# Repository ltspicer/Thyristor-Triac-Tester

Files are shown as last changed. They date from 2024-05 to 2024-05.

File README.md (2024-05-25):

# Thyristor-Triac-Tester

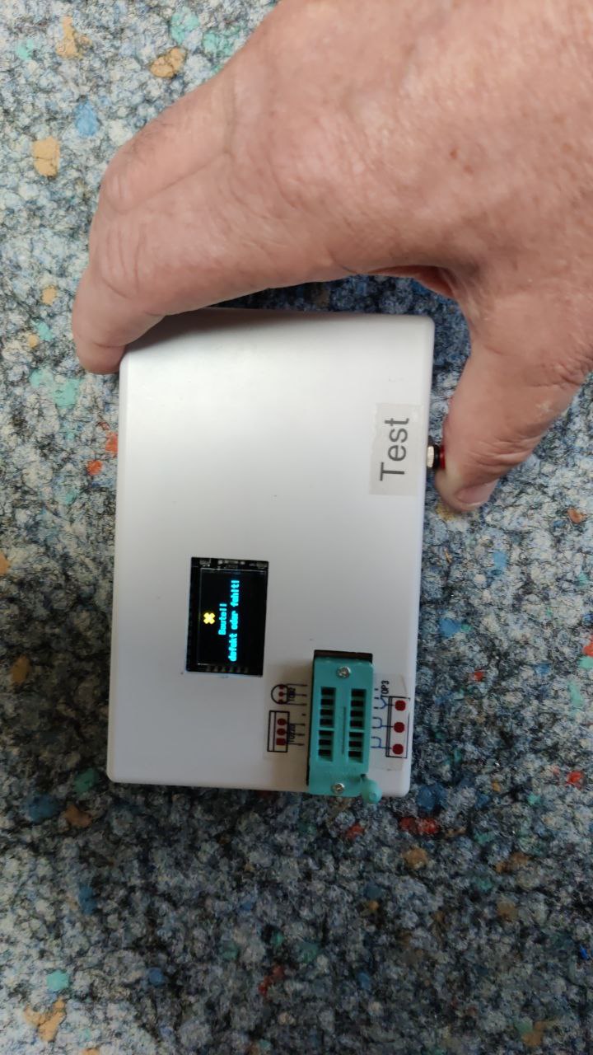
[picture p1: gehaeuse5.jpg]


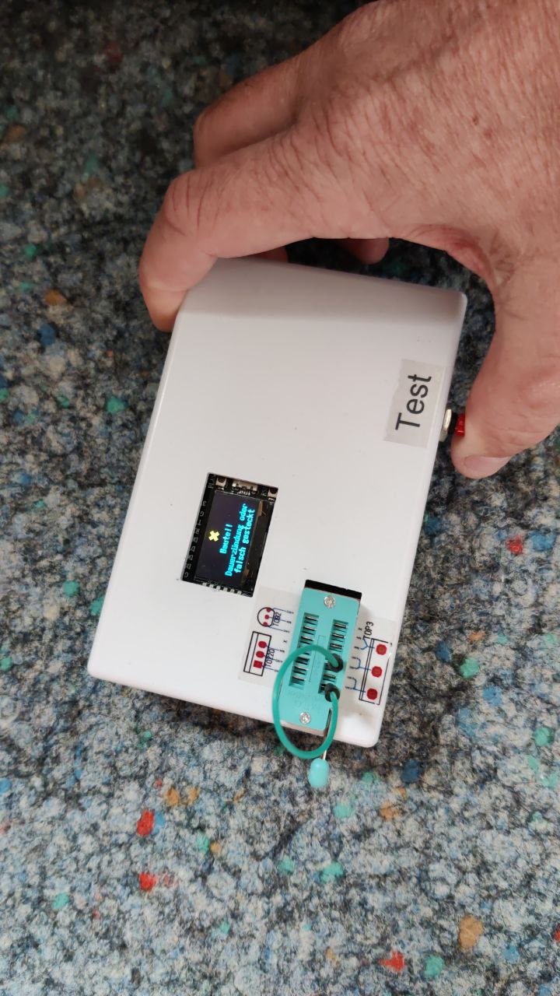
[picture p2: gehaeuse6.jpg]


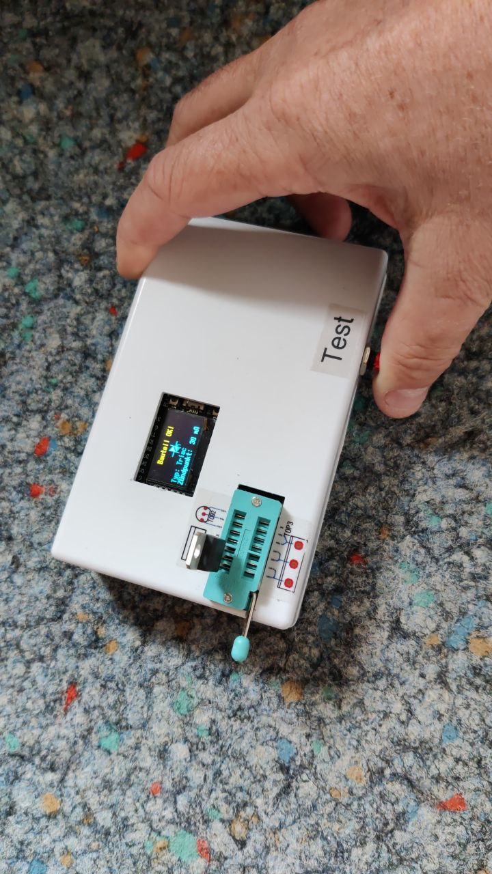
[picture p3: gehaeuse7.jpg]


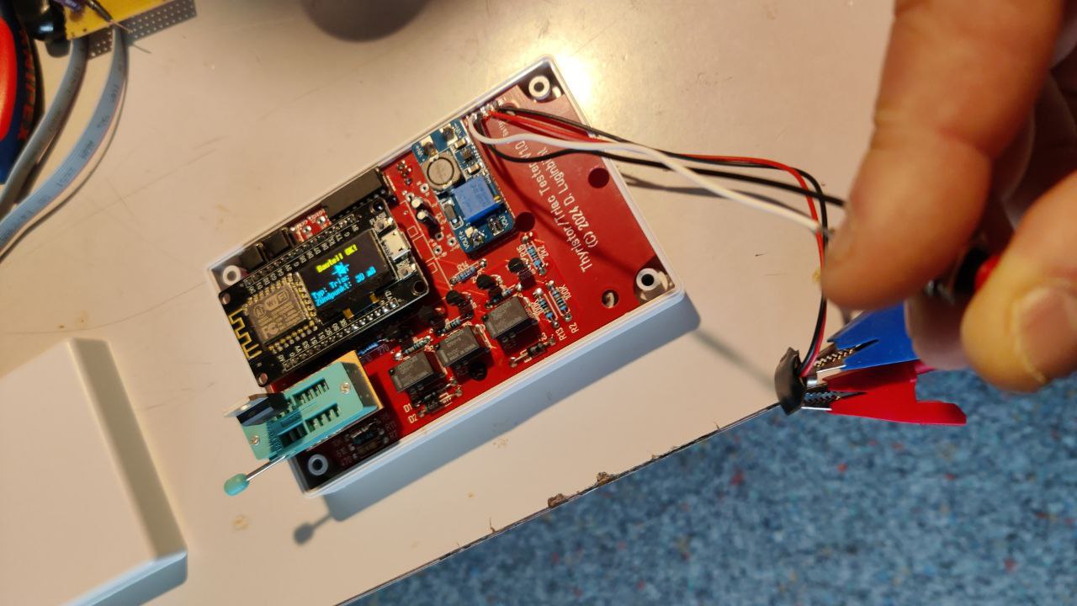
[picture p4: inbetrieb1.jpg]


## Original Text:

Dieses Testgerät kann Thyristoren und Triacs bis zu hohen Zündströmen testen.

Thyristoren und Triacs testen ist das Einzige, was der LCR-TC2 ( https://de.aliexpress.com/item/1005004205300336.html ) nicht kann.

Grösste Baustelle ist noch die Distanzerhöhung des IC Testsockels. Dieser sollte höher als das Display sein.
Leider greiffen die kurzen Beinchen nicht stabil genug in einem Pinheader.

Die Zwischenplatte ist nur, um den IC Testsockel auf ein Niveau höher als das Display zu bringen.
Ohne Gehäuse kann der IC Testsockel direkt auf das PCB gelötet werden.

Die Schaltkreise und PCB Layouts sind mit Target3001medium erstellt worden und können mit Target3001discover geöffnet werden. Target3001discover ist kostenlos!

Der StepUp ist auf **18V** zustellen!

Die ino Datei ist mittels **Arduino IDE** auf den ESP8266 zuschreiben.

Ich habe zwar noch rote PCBs V1.0 auf Lager (für Interessenten). Falls aber eine grössere Sammelbestellung zustande kommt, werde ich V1.1 PCBs in Auftrag geben. Ich werde dann auch die Zwischen-PCBs für den IC Testsockel bestellen.

Dieses Projekt ist hier zuhause: https://www.ltspiceusers.ch/threads/baue-mir-einen-thyristor-triac-tester-mit-einem-esp8266-mit-oled-display.2739/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

Die **2 zip** sind die **Gerber** Dateien.

Falls ein Triac als Thyristor erkannt wird, ist dieser Triac defekt!

## English (DeepL translator):

This tester can test thyristors and triacs up to high ignition currents.

Testing thyristors and triacs is the only thing the LCR-TC2 ( https://de.aliexpress.com/item/1005004205300336.html ) cannot do.

The biggest problem is increasing the distance of the IC test socket. This should be higher than the display.
Unfortunately, the short legs do not grip firmly enough in a pin header.

The intermediate plate is only to bring the IC test socket to a level higher than the display.
Without the housing, the IC test socket can be soldered directly onto the PCB.

The circuits and PCB layouts have been created with Target3001medium and can be opened with Target3001discover. Target3001discover is free!

The StepUp must be set to **18V**!

The ino file is to be written to the ESP8266 with **Arduino IDE**.

I still have red PCBs V1.0 in stock (for interested parties). However, if a larger collective order is placed, I will order V1.1 PCBs. I will then also order the intermediate PCBs for the IC test socket.

This project is here @home: https://www.ltspiceusers.ch/threads/baue-mir-einen-thyristor-triac-tester-mit-einem-esp8266-mit-oled-display.2739/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

The **2 zip** are the **Gerber** files.

If a triac is recognized as a thyristor, this triac is defective!

--------------------------------

## Stückliste:

1x  ESP8266 NodeMCU mit OLED        https://de.aliexpress.com/item/1005005470719229.html

1x  Gehäuse 125x80x32mm             https://de.aliexpress.com/item/1005005448610944.html

2x  Pinheader 15pol weiblich        https://de.aliexpress.com/item/1005001418544370.html

3x  Omron Relais G5V-1-5VDC         https://de.aliexpress.com/item/1005005743754968.html

1x  L293B H-Bridge                  https://de.aliexpress.com/item/1005006253986033.html

1x  StepUp MT3608                   https://de.aliexpress.com/item/1005006532445571.html

1x  14pin IC Testsockel             https://de.aliexpress.com/item/1005006117085994.html

2x  4N35 Optokoppler

1x  7805 5V Spannungsregler

5x  2N7000 Kleinleistungs-FET

3x  1N4007 Diode (oder ähnlich. Nur für Freilauf)

2x  IC Sockel DIP6

1x  IC Sockel DIP16

1x  Einbau Drucktaster (Schliesser)

1x  9V Batterie Anschlusskabel

1x  9V Batterie

2x  Elko 4.7µF 50V (mindestens 16V)

5x  Widerstand 100 kOhm

3x  Widerstand 10 kOhm

2x  Widerstand 2.2 kOhm

1x  Widerstand 510 Ohm

1x  Widerstand 470 Ohm

1x  Widerstand 270 Ohm

1x  Widerstand 60 Ohm

1x  Widerstand 22 Ohm

2x  Pinheader 7pol weiblich (für IC Testsockel)

Pinleiste 1 reihig zuschneidbar (für StepUp, IC Testsockel und optionale Testpins)

### Die Bauteile kosten keine 20€ (exkl Batterie. Die ist wohl das teuerste Bauteil)!

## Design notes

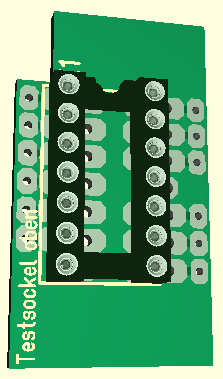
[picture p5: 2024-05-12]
pcb2.png

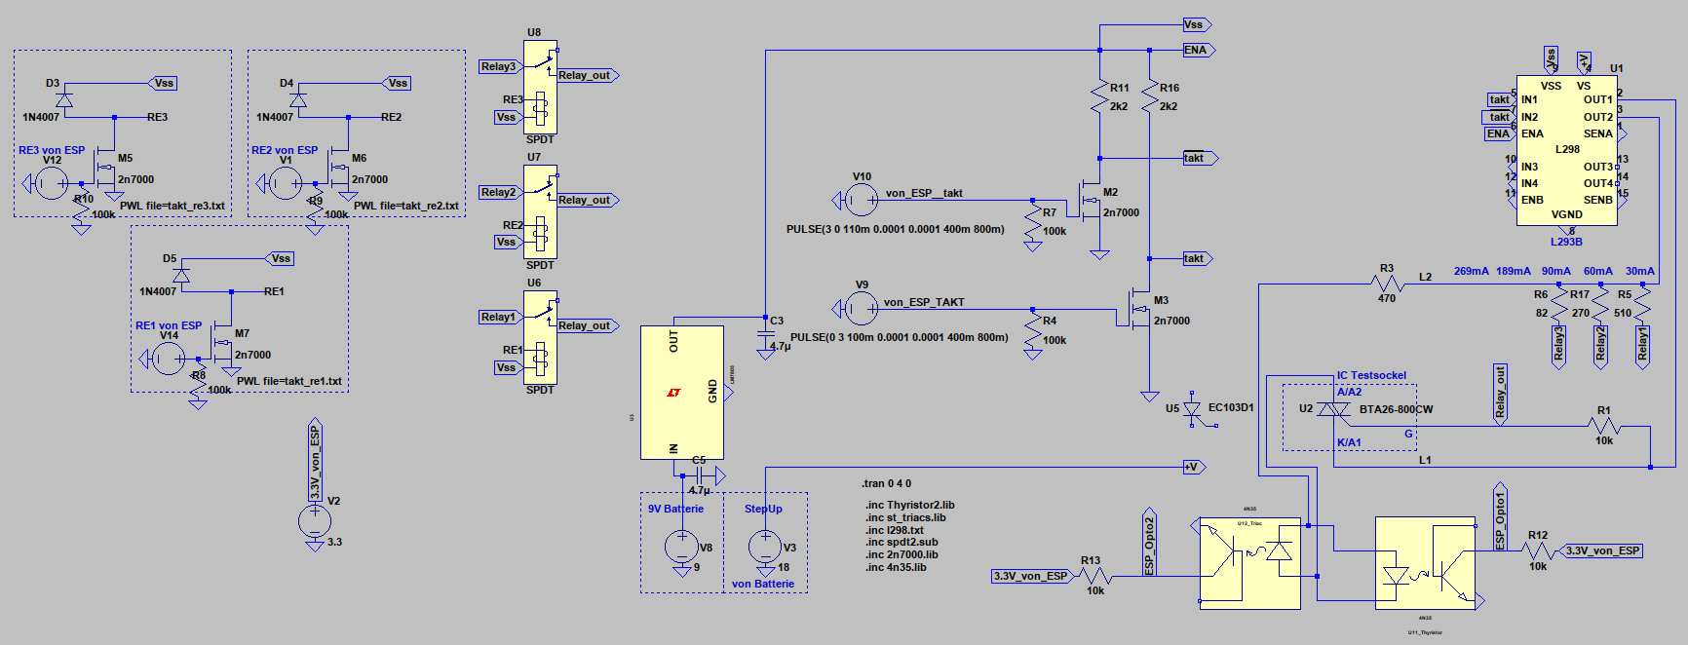
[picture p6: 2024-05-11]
ltspice_simulation.png

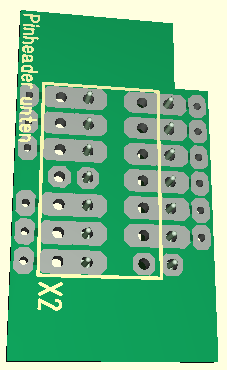
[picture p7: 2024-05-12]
pcb22.png

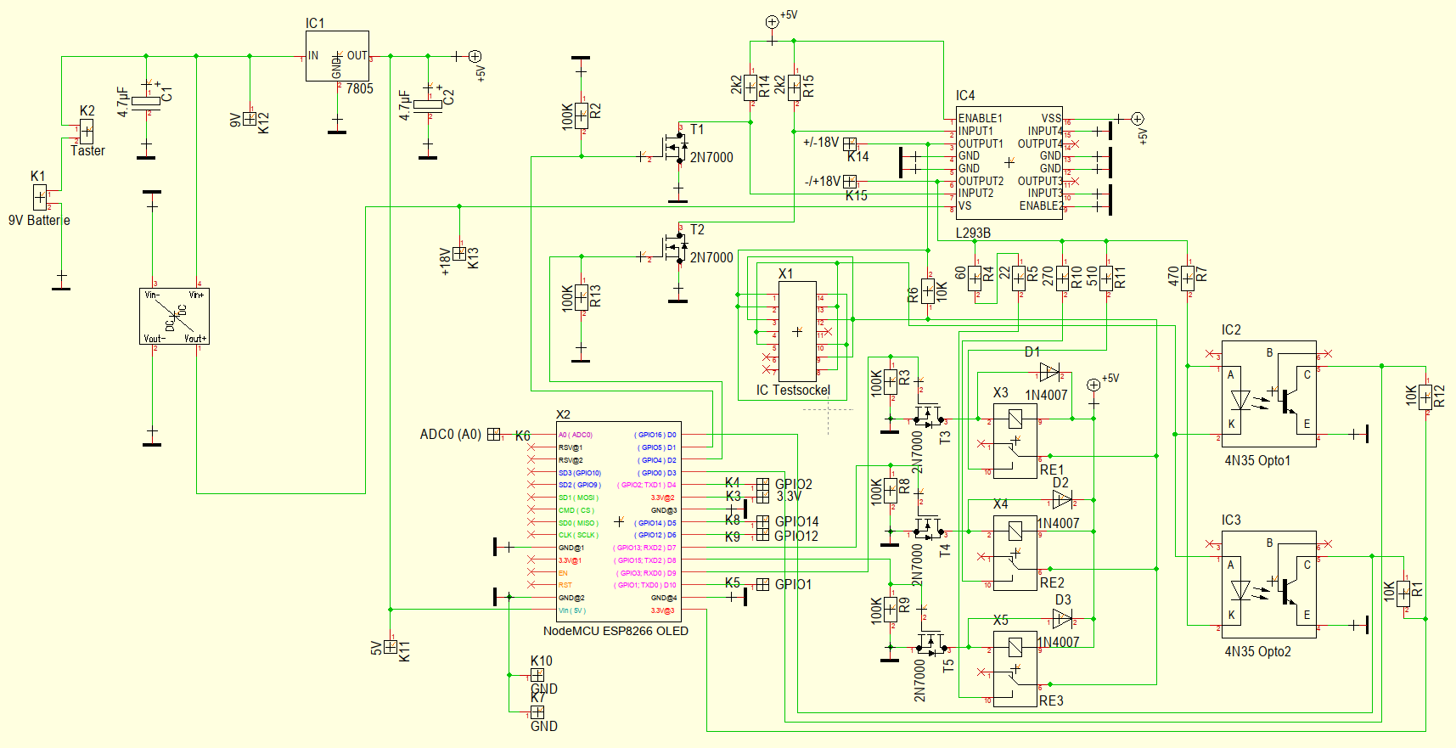
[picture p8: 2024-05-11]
schema_target3001.png

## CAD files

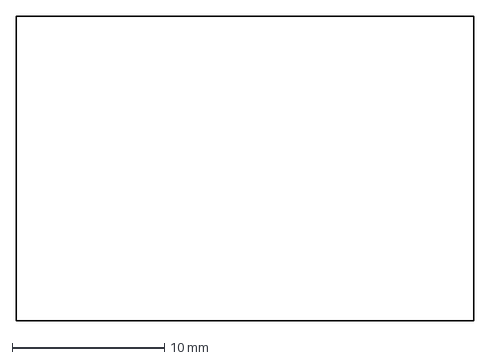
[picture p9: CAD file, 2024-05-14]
gehaeuse/display.dxf
30.0 x 20.0 mm

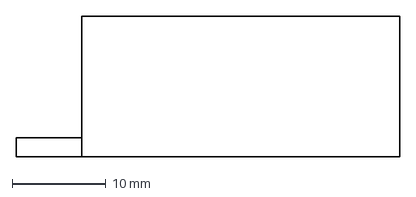
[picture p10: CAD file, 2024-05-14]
gehaeuse/ic_sockel.dxf
41.0 x 15.0 mm

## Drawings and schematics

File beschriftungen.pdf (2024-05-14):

# Test

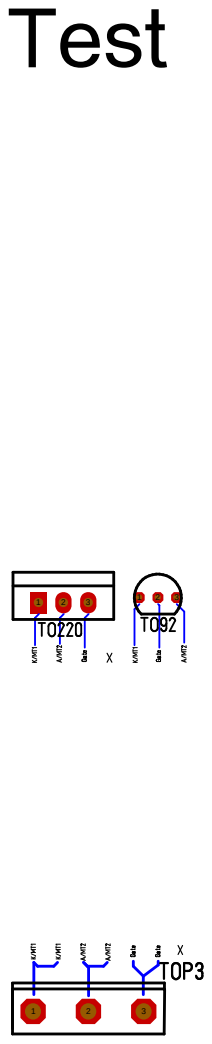
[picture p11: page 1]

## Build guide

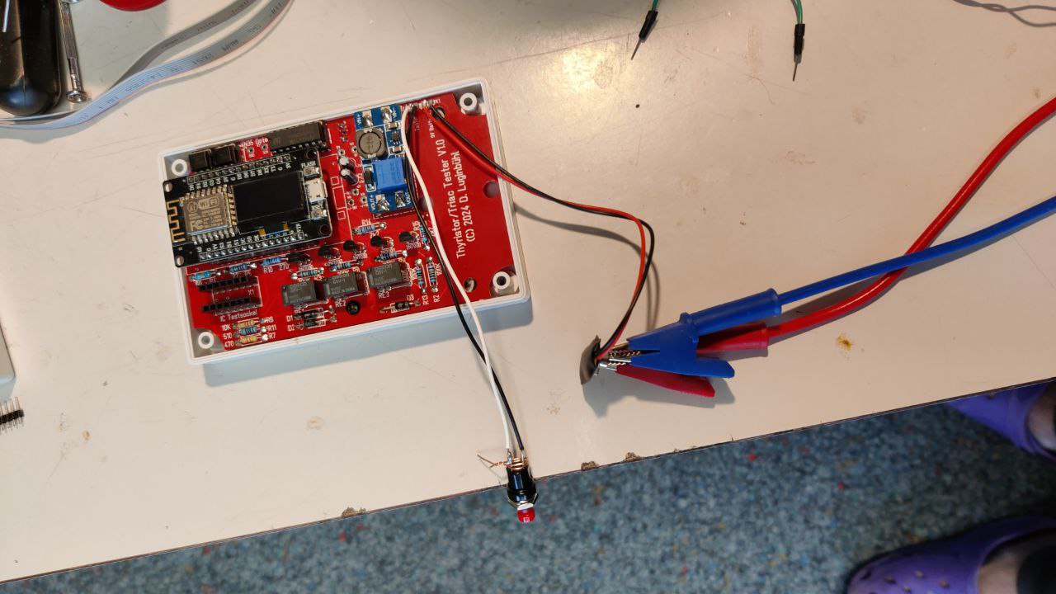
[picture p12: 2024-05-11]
aufbau2.jpg

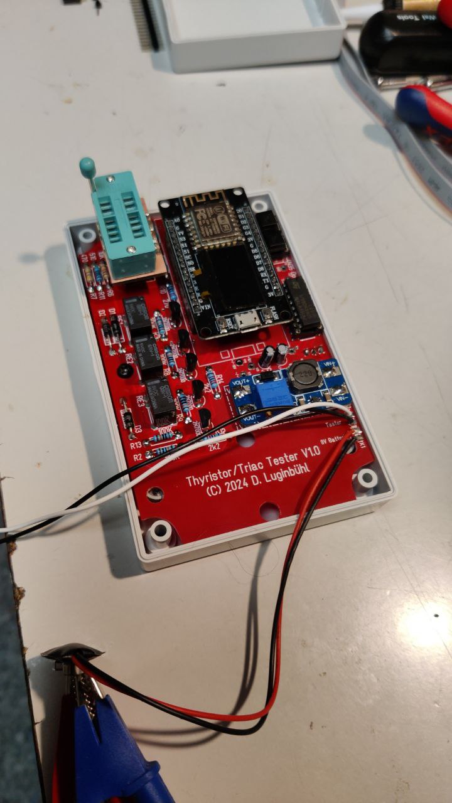
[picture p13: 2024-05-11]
aufbau3.jpg

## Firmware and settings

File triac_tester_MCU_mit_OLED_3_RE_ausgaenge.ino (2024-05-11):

// Thyristor/Triac Tester
// Daniel Luginbühl
// V1.1 (C) 2024

// https://github.com/olikraus/u8g2/wiki

#include <Arduino.h>
#include <U8g2lib.h>

#define SCREEN_WIDTH 128
#define SCREEN_HEIGHT 64
#define OLED_RESET -1
#define SCREEN_ADDRESS 0x3C

// sda = 12
// scl = 14

U8G2_SSD1306_128X64_NONAME_F_SW_I2C u8g2(U8G2_R0,14,12,U8X8_PIN_NONE);

// GPIOs definieren
const int RE1  =  3;           // Relais Ausgang 1
const int RE2  = 13;           // Relais Ausgang 2
const int RE3  = 15;           // Relais Ausgang 3

const int TAKT =  4;           // Takt        für Umpolung
const int takt =  5;           // Takt invers für Umpolung

const int Opto1  =  0;         // Opto1  mit PullUp
const int Opto2  = 16;         // Opto2  mit PullUp

const int debug = 2;           // Pin an GND schaltet DEBUG ein

// Diverse Koordinaten für Grafikausgabe
const int x_offset = 47;
const int oben = 17;
const int y_mitte = 27;
const int unten = 37;
const int triac1 = 23;
const int triac2 = 31;

const int zeile0 = 14;
const int zeile1 = 32;
const int zeile2 = 49;
const int zeile3 = 62;

// Diverse Variabeln
int gezuendet = 0;             // mA für Zündung
boolean positiv = false;       // Positive Halbwelle
boolean negativ = false;       // Negative Halbwelle
boolean DEBUG = false;         // Debug Status ein/aus

void setup() {
  Serial.begin(9600);

  u8g2.begin();
  // https://github.com/olikraus/u8g2/wiki/fntgrpx11#7x14b
  u8g2.setFont(u8g2_font_7x14B_tf);

  pinMode(RE1, OUTPUT);
  pinMode(RE2, OUTPUT);
  pinMode(RE3, OUTPUT);
  pinMode(TAKT, OUTPUT);
  pinMode(takt, OUTPUT);
  pinMode(Opto1, INPUT_PULLUP);
  pinMode(Opto2, INPUT_PULLUP);
  pinMode(debug, INPUT_PULLUP);

  digitalWrite(TAKT, LOW);
  digitalWrite(takt, LOW);
  digitalWrite(RE1,LOW);
  digitalWrite(RE2,LOW);
  digitalWrite(RE3,LOW);
}

void loop() {

  u8g2.clearBuffer();
  u8g2.drawUTF8(0, zeile0, "Prüfung läuft...");

  if (digitalRead(debug) == LOW) {
    DEBUG = true;
  } else {
    DEBUG = false;
  }

  // Bauteil Dauerzündung?
  u8g2.drawUTF8(0, zeile1, "Dauerzündung?");
  u8g2.sendBuffer();  
  delay(100);
  for (int d = 0; d < 2; d++) {
    if (gezuendet == 0 or gezuendet == 500) {
      umpolen();
      delay(200);
      if (OptosAbfragen()) {
        gezuendet = 500;
      }
    }
  }
  if (gezuendet == 500) {
    positiv = false;
    negativ = false;
    u8g2.clearBuffer();
    goto defekt;
  }

  // 30mA Zündung
  u8g2.clearBuffer();
  u8g2.drawUTF8(0, zeile0, "Prüfung läuft...");
  u8g2.drawUTF8(0, zeile1, "30mA Zündung");
  u8g2.sendBuffer();
  for (int d = 0; d < 2; d++) {
    if (gezuendet == 0 or gezuendet == 30) {
      umpolen();
      digitalWrite(RE1,HIGH);
      if (DEBUG) {
        Serial.println("RE1 HIGH");
      }  
      delay(200);
      digitalWrite(RE1,LOW);
      if (DEBUG) {
        Serial.println("RE1 LOW");
      }  
      delay(100);
      if (OptosAbfragen()) {
        gezuendet = 30;
      }
    }
  }
  if (gezuendet == 30) {
    goto fertig;
  }

  // 60mA Zündung
  u8g2.clearBuffer();
  u8g2.drawUTF8(0, zeile0, "Prüfung läuft...");
  u8g2.drawUTF8(0, zeile1, "60mA Zündung");
  u8g2.sendBuffer();  
  for (int d = 0; d < 2; d++) {
    if (gezuendet == 0 or gezuendet == 60) {
      umpolen();
      digitalWrite(RE2,HIGH);
      if (DEBUG) {
        Serial.println("RE2 HIGH");
      }  
      delay(200);
      digitalWrite(RE2,LOW);
      if (DEBUG) {
        Serial.println("RE2 LOW");
      }  
      delay(100);
      if (OptosAbfragen()) {
        gezuendet = 60;
      }
    }
  }
  if (gezuendet == 60) {
    goto fertig;
  }

  // 90mA Zündung
  u8g2.clearBuffer();
  u8g2.drawUTF8(0, zeile0, "Prüfung läuft...");
  u8g2.drawUTF8(0, zeile1, "90mA Zündung");
  u8g2.sendBuffer();
  for (int d = 0; d < 2; d++) {
    if (gezuendet == 0 or gezuendet == 90) {
      umpolen();
      digitalWrite(RE1,HIGH);
      digitalWrite(RE2,HIGH);
      if (DEBUG) {
        Serial.println("RE1 HIGH");
        Serial.println("RE2 HIGH");
      }  
      delay(200);
      digitalWrite(RE1,LOW);
      digitalWrite(RE2,LOW);
      if (DEBUG) {
        Serial.println("RE1 LOW");
        Serial.println("RE2 LOW");
      }  
      delay(100);
      if (OptosAbfragen()) {
        gezuendet = 90;
      }
    }
  }
  if (gezuendet == 90) {
    goto fertig;
  }

  // 189mA Zündung
  u8g2.clearBuffer();
  u8g2.drawUTF8(0, zeile0, "Prüfung läuft...");
  u8g2.drawUTF8(0, zeile1, "189mA Zündung");
  u8g2.sendBuffer();
  for (int d = 0; d < 2; d++) {
    if (gezuendet == 0 or gezuendet == 189) {
      umpolen();
      digitalWrite(RE3,HIGH);
      if (DEBUG) {
        Serial.println("RE3 HIGH");
      }  
      delay(200);
      digitalWrite(RE3,LOW);
      if (DEBUG) {
        Serial.println("RE3 LOW");
      }  
      delay(100);
      if (OptosAbfragen()) {
        gezuendet = 189;
      }
    }
  }
  if (gezuendet == 189) {
    goto fertig;
  }

  // 269mA Zündung
  u8g2.clearBuffer();
  u8g2.drawUTF8(0, zeile0, "Prüfung läuft...");
  u8g2.drawUTF8(0, zeile1, "269mA Zündung");
  u8g2.sendBuffer();
  for (int d = 0; d < 2; d++) {
    if (gezuendet == 0 or gezuendet == 269) {
      umpolen();
      digitalWrite(RE1,HIGH);
      digitalWrite(RE2,HIGH);
      digitalWrite(RE3,HIGH);
      if (DEBUG) {
        Serial.println("RE1 HIGH");
        Serial.println("RE2 HIGH");
        Serial.println("RE3 HIGH");
      }  
      delay(200);
      digitalWrite(RE1,LOW);
      digitalWrite(RE2,LOW);
      digitalWrite(RE3,LOW);
      if (DEBUG) {
        Serial.println("RE1 LOW");
        Serial.println("RE2 LOW");
        Serial.println("RE3 LOW");
      }  
      delay(100);
      if (OptosAbfragen()) {
        gezuendet = 269;
      }
    }
  }

  fertig:

  u8g2.clearBuffer();

  if (DEBUG) {
    if (!digitalRead(Opto1) == HIGH) {
      Serial.println("Opto1=1 (Positive Halbwelle)");
    }
    if (!digitalRead(Opto2) == HIGH) {
      Serial.println("Opto2=1 (Negative Halbwelle)");
    }
  }

  // Display Ausgabe

  // https://github.com/olikraus/u8g2/wiki/u8g2reference

  if (gezuendet > 0) {
    //u8g2.setCursor(0, zeile2);
    //u8g2.print("Zündpunkt: ");
    u8g2.drawUTF8(0, zeile3, "Zündpunkt: ");
    u8g2.setCursor(10*8, zeile3);
    u8g2.print(gezuendet);
    u8g2.print(" mA");
    u8g2.setCursor(0, zeile2);
    u8g2.print("Typ: ");
    if (positiv != negativ) {
      u8g2.print("Thyristor");

      u8g2.drawLine(x_offset   , y_mitte  , x_offset+10, y_mitte);
      u8g2.drawLine(x_offset+20, y_mitte  , x_offset+30, y_mitte);
      u8g2.drawLine(x_offset+20, oben+3   , x_offset+20, unten-3);
      u8g2.drawLine(x_offset+20, y_mitte+1, x_offset+25, y_mitte+4);
      u8g2.drawLine(x_offset+25, y_mitte+4, x_offset+25, unten-4);

      u8g2.drawTriangle(x_offset+10,oben+3, x_offset+10,unten-3, x_offset+20,y_mitte);

    } else {
      u8g2.print("Triac");

      u8g2.drawLine(x_offset   , y_mitte  , x_offset+10, y_mitte);
      u8g2.drawLine(x_offset+20, y_mitte  , x_offset+30, y_mitte);
      u8g2.drawLine(x_offset+20, oben     , x_offset+20, unten);
      u8g2.drawLine(x_offset+10, oben     , x_offset+10, unten);
      u8g2.drawLine(x_offset+20, y_mitte+1, x_offset+25, y_mitte+4);
      u8g2.drawLine(x_offset+25, y_mitte+4, x_offset+25, unten-2);

      u8g2.drawTriangle(x_offset+11,oben+1,    x_offset+11,y_mitte+1, x_offset+21,triac1);
      u8g2.drawTriangle(x_offset+20,y_mitte-1, x_offset+20,unten-1,   x_offset+10,triac2);

    }

    if (DEBUG) {
      Serial.print("Gezündet mit ");
      Serial.print(gezuendet);
      Serial.println(" mA");
      Serial.print("Typ: ");
      if (positiv != negativ) {
        Serial.println("Thyristor");
      } else {
        Serial.println("Triac");
      }
    }
  }

  defekt:

  digitalWrite(TAKT, LOW);
  digitalWrite(takt, LOW);
  if (positiv == false and negativ == false) {
    u8g2.setCursor(5*8, zeile1);
    u8g2.print("Bauteil");
    if (gezuendet == 500) {
      u8g2.drawUTF8(0, zeile2, " Dauerzündung oder");
      u8g2.setCursor(0, zeile3);
      u8g2.print("  falsch gesteckt");
    } else {
      u8g2.setCursor(0, zeile2);
      u8g2.print("defekt oder fehlt!");
    }  
    u8g2.setFont(u8g2_font_unifont_t_symbols);  // Zeichensatz für Kreuz
    u8g2.drawGlyph(56, 15, 0x2716);	            // Kreuz zeichnen
    u8g2.setFont(u8g2_font_7x14B_tf);    // Zeichensatz zurücksetzen

    if (DEBUG) {
      Serial.println("Kein Bauteil oder defekt");
    }
  } else {
    u8g2.setCursor(28, zeile0);
    u8g2.print("Bauteil OK!");
    if (DEBUG) {
      Serial.println("Bauteil OK!");
    }
  }
  u8g2.sendBuffer();
  if (DEBUG) {
    gezuendet = 0;                       // mA für Zündung
    positiv = false;                     // Positive Halbwelle
    negativ = false;                     // Negative Halbwelle
    delay(5000);
  } else {
    do {                                 // Endlosschleife
      delay(5000);
      if (digitalRead(debug) == LOW) {
        Serial.println("Debug eingeschaltet");
        break;
      }
    } while (true);    
  }  
}

boolean OptosAbfragen() {
  boolean Opto1in = !digitalRead(Opto1);
  boolean Opto2in = !digitalRead(Opto2);
  if (Opto1in == HIGH) {
    positiv = true;
  }
  if (Opto2in == HIGH) {  
    negativ = true;
  }
  if (Opto1in == HIGH or Opto2in == HIGH) {
    return true;
  }  
  return false;
}

void umpolen() {
  digitalWrite(TAKT, !digitalRead(TAKT));
  delay(90);
  digitalWrite(takt, !digitalRead(TAKT));
  delay(10);
}

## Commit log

2024-05-12 Add files via upload
    Gerber files
2024-05-14 Add files via upload
    Gehäuseausschnitte
    [display.dxf, ic_sockel.dxf]
